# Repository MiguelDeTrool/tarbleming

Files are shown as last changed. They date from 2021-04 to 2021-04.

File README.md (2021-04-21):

# tarbleming
Arduino Nano based random looping sequencer Eurorack module

Tarbleming

This is my take on the Music Thing Modular Turing Machine/Mutable Instruments Marbles, in an easier to implement fashion, with easily available through-hole parts. I must warn anyone attempting this that I have not tested these exact PCBs, only an earlier prototype, that I then made minor modifications to for this version. I am quite confident that they will work, and feel free to send me a message if you decide to try this out. I wouldn't recommend this to a complete beginner, as I have provided no build guide.

You'll also notice a manual is missing. Basic functionality to get up and running is send it a clock signal. Each sequence, wether Gate or CV, can have it's own length. Tap the corresponding button for however many steps you want, then do a quick double tap to confirm that value. Turn a sequence's Randomness knob fully clockwise for it to constantly change, and fully counter-clockwise for it to lock in a looping pattern. And again, if you have questions, feel free to send a message.

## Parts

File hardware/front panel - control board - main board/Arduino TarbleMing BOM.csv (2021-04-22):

Id | Designator | Package | Quantity | Designation
1 | R4,R5,R6,R10,R8,R7,R1 | R_Axial_DIN0207_L6.3mm_D2.5mm_P7.62mm_Horizontal | 7 | 10K
2 | C14,C9,C8,C7,C6 | C_Disc_D3.8mm_W2.6mm_P2.50mm | 5 | 100n
3 | R32,R31 | R_Axial_DIN0207_L6.3mm_D2.5mm_P7.62mm_Horizontal | 2 | 1000
4 | Q4,Q5,Q3,Q2,Q1 | TO-92_Inline | 5 | 2N3904
5 | U5 | DIP-8_W7.62mm_Socket_LongPads | 1 | TL082
6 | U7 | DIP-8_W7.62mm_Socket_LongPads | 1 | MCP4822
7 | U4,U3 | DIP-8_W7.62mm_Socket_LongPads | 2 | MCP6002-xP
8 | J23,J22 | PinHeader_1x14_P2.54mm_Vertical | 2 | Conn_01x14
9 | J21,J20 | PinHeader_1x13_P2.54mm_Vertical | 2 | Conn_01x13
10 | R23,R30,R29,R27,R26,R28,R21,R20,R19,R18,R16,R12,R11,R9,R3,R2,R22 | R_Axial_DIN0207_L6.3mm_D2.5mm_P7.62mm_Horizontal | 17 | 100K
11 | D2,D1 | D_DO-15_P10.16mm_Horizontal | 2 | 1N4001
12 | SW4,SW3,SW2,SW1 | DPDT_Momentary_Push_Button_Switch | 4 | SW_Push_DPDT
13 | D5,D4,D3 | D_DO-35_SOD27_P7.62mm_Horizontal | 3 | 1N4148
14 | J12,J11,J10,J9,J8,J7,J6,J5,J4,J2,J1 | ModdedThonkiconn | 11 | ThonkiConn
15 | U6 | Arduino_Nano | 1 | Arduino_Nano_v3.x
16 | U2 | TO-220-3_Horizontal_TabDown | 1 | L7805
17 | U1 | TO-92_Inline | 1 | LM4040LP-5 (maybe could be replaced by a 5v zener diode in a pinch?)
18 | RV5,RV4,RV3,RV2,RV1 | ModdedPotentiometer | 5 | 10K
19 | R25,R24 | R_Axial_DIN0207_L6.3mm_D2.5mm_P7.62mm_Horizontal | 2 | 3300
20 | R14,R15,R17 | R_Axial_DIN0207_L6.3mm_D2.5mm_P7.62mm_Horizontal | 3 | 330
21 | R13 | R_Axial_DIN0207_L6.3mm_D2.5mm_P7.62mm_Horizontal | 1 | 50k
22 | J3 | PinHeader_2x05_P2.54mm_Vertical | 1 | Eurorack Power Header
23 | D8,D7,D6 | LED_D3.0mm | 3 | LED
24 | C3,C1 | CP_Radial_D6.3mm_P2.50mm | 2 | 100uF
25 | C13,C12,C11,C10,C2 | C_Disc_D3.8mm_W2.6mm_P2.50mm | 5 | 1n
26 | C5 | C_Disc_D3.8mm_W2.6mm_P2.50mm | 1 | 10n
27 | C4 | C_Disc_D3.8mm_W2.6mm_P2.50mm | 1 | 0.47µ

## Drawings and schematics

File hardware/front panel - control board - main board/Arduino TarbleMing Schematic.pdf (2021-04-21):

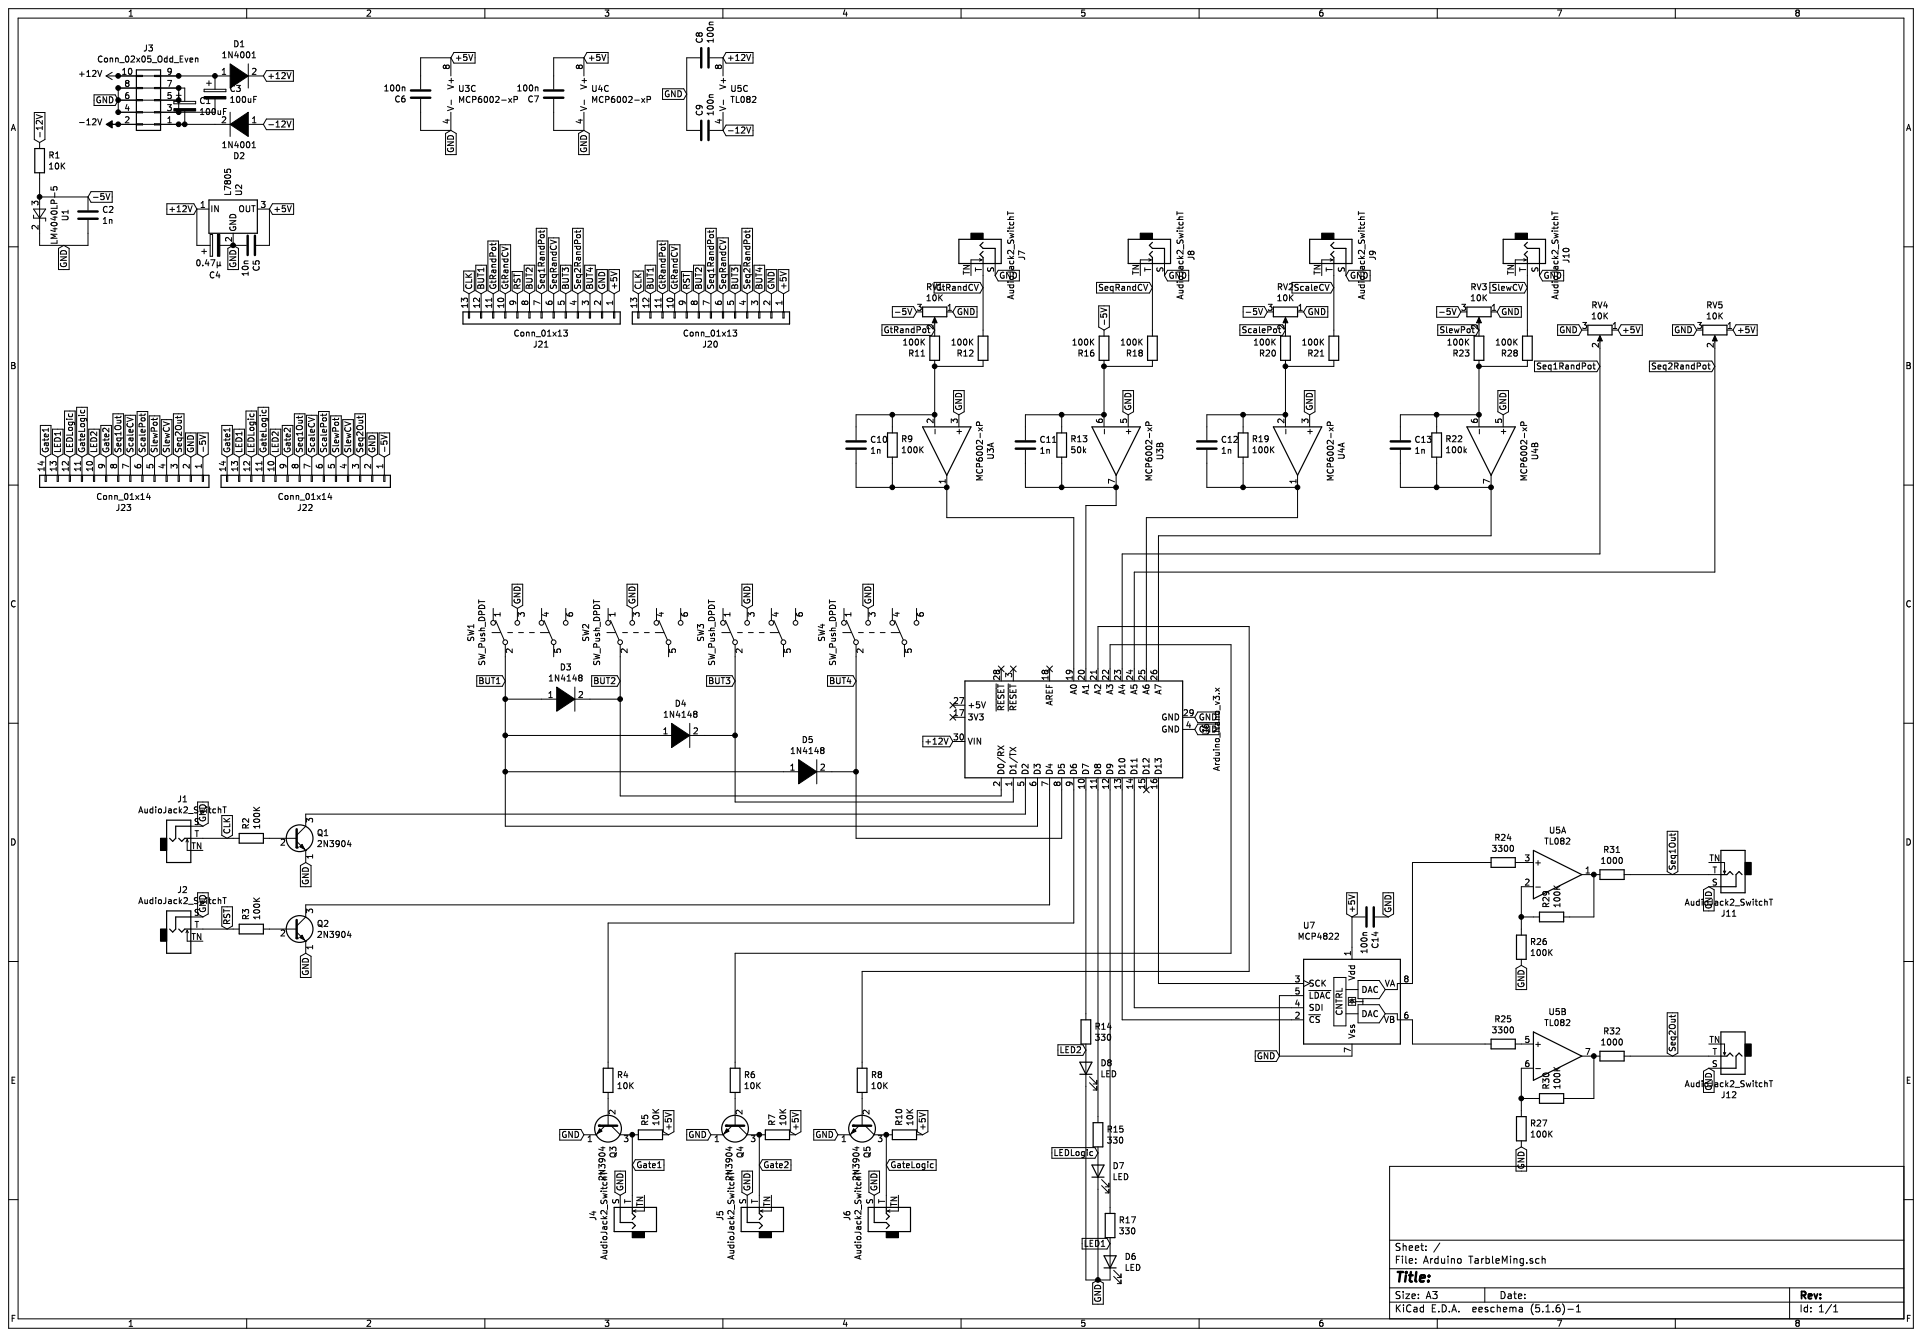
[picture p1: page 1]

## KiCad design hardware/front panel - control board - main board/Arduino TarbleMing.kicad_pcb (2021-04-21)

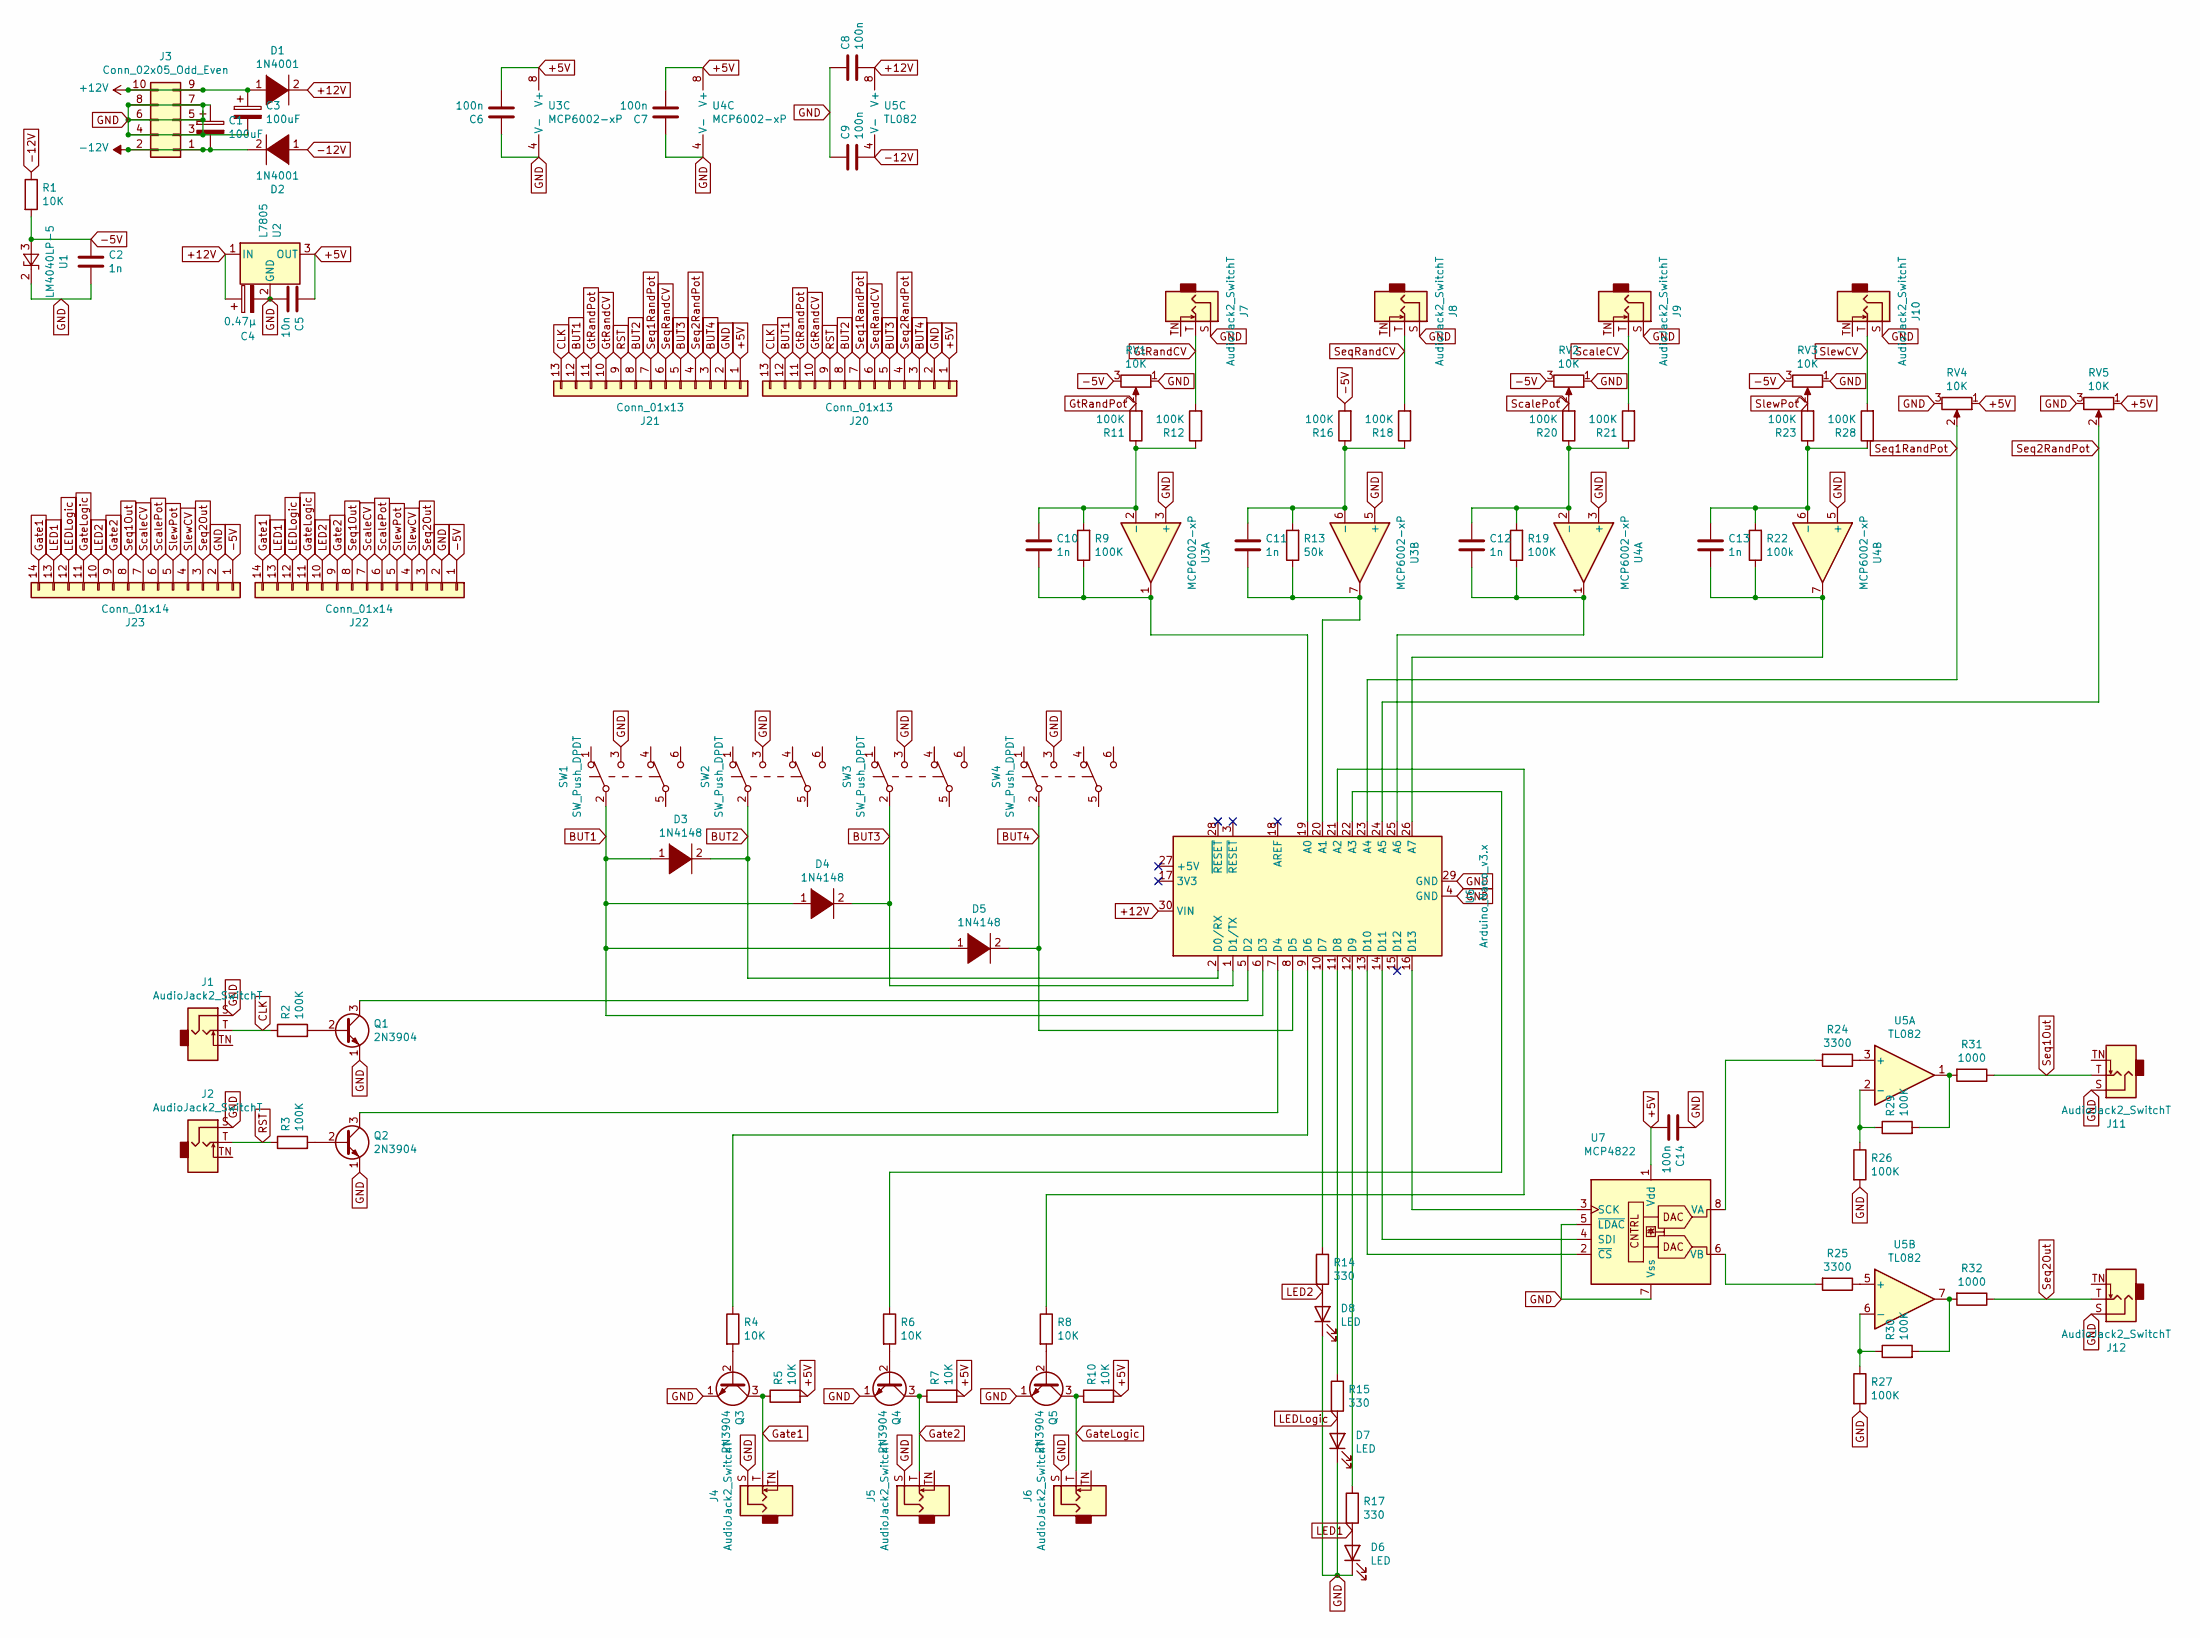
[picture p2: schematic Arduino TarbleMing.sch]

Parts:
C1, C3: 100uF; CP_Radial_D6.3mm_P2.50mm
C2, C10, C11, C12, C13: 1n; C_Disc_D3.8mm_W2.6mm_P2.50mm
C4: 0.47µ; C_Disc_D3.8mm_W2.6mm_P2.50mm
C5: 10n; C_Disc_D3.8mm_W2.6mm_P2.50mm
C6, C7, C8, C9, C14: 100n; C_Disc_D3.8mm_W2.6mm_P2.50mm
D1, D2: 1N4001; D_DO-15_P10.16mm_Horizontal
D3, D4, D5: 1N4148; D_DO-35_SOD27_P7.62mm_Horizontal
D6, D7, D8: LED; LED_D3.0mm
J1, J2, J4, J5, J6, J7, J8, J9, J10, J11, J12: AudioJack2_SwitchT; ModdedThonkiconn
J3: Conn_02x05_Odd_Even; PinHeader_2x05_P2.54mm_Vertical
J20, J21: Conn_01x13; PinHeader_1x13_P2.54mm_Vertical
J22, J23: Conn_01x14; PinHeader_1x14_P2.54mm_Vertical
Q1, Q2, Q3, Q4, Q5: 2N3904; TO-92_Inline
R1, R4, R5, R6, R7, R8, R10: 10K; R_Axial_DIN0207_L6.3mm_D2.5mm_P7.62mm_Horizontal
R2, R3, R9, R11, R12, R16, R18, R19, R20, R21, R23, R26, R27, R28, R29, R30: 100K; R_Axial_DIN0207_L6.3mm_D2.5mm_P7.62mm_Horizontal
R13: 50k; R_Axial_DIN0207_L6.3mm_D2.5mm_P7.62mm_Horizontal
R14, R15, R17: 330; R_Axial_DIN0207_L6.3mm_D2.5mm_P7.62mm_Horizontal
R22: 100k; R_Axial_DIN0207_L6.3mm_D2.5mm_P7.62mm_Horizontal
R24, R25: 3300; R_Axial_DIN0207_L6.3mm_D2.5mm_P7.62mm_Horizontal
R31, R32: 1000; R_Axial_DIN0207_L6.3mm_D2.5mm_P7.62mm_Horizontal
RV1, RV2, RV3, RV4, RV5: 10K; ModdedPotentiometer
SW1, SW2, SW3, SW4: SW_Push_DPDT; DPDT_Momentary_Push_Button_Switch
U1: LM4040LP-5; TO-92_Inline
U2: L7805; TO-220-3_Horizontal_TabDown
U3, U4: MCP6002-xP; DIP-8_W7.62mm_Socket_LongPads
U5: TL082; DIP-8_W7.62mm_Socket_LongPads
U6: Arduino_Nano_v3.x; Arduino_Nano
U7: MCP4822; DIP-8_W7.62mm_Socket_LongPads

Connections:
+5V: C5.1, C6.2, C7.2, C14.2, J20.1, J21.1, R5.2, R7.2, R10.2, RV4.1, RV5.1, U2.3 (OUT), U3.8 (V+), U4.8 (V+), U7.1 (Vdd)
+12V: C3.1, C4.1, C8.2, D1.1 (K), D1.2 (A), J3.9, J3.10, U2.1 (IN), U5.8 (V+), U6.30 (VIN)
-5V: C2.1, J22.1, J23.1, R1.2, R16.2, RV1.3, RV2.3, RV3.3, U1.3 (A)
-12V: C1.2, C9.2, D2.1 (K), D2.2 (A), J3.1, J3.2, R1.1, U5.4 (V-)
BUT1: D3.1 (K), D4.1 (K), D5.1 (K), J20.12, J21.12, SW1.2 (B), U6.6 (D3)
BUT2: D3.2 (A), J20.8, J21.8, SW2.2 (B), U6.2 (D0/RX)
BUT3: D4.2 (A), J20.5, J21.5, SW3.2 (B), U6.1 (D1/TX)
BUT4: D5.2 (A), J20.3, J21.3, SW4.2 (B), U6.8 (D5)
CLK: J1.T, J20.13, J21.13, R2.1
GND: C1.1, C2.2, C3.2, C4.2, C5.2, C6.1, C7.1, C8.1, C9.1, C14.1, D6.1 (K), D7.1 (K), D8.1 (K), J1.S, J2.S, J3.3, J3.4, J3.5, J3.6, J3.7, J3.8, J4.S, J5.S, J6.S, J7.S, J8.S, J9.S, J10.S, J11.S, J12.S, J20.2, J21.2, J22.2, J23.2, Q1.1 (E), Q2.1 (E), Q3.1 (E), Q4.1 (E), Q5.1 (E), R26.2, R27.2, RV1.1, RV2.1, RV3.1, RV4.3, RV5.3, SW1.3 (C), SW2.3 (C), SW3.3 (C), SW4.3 (C), U1.2 (K), U2.2 (GND), U3.3 (+), U3.4 (V-), U3.5 (+), U4.3 (+), U4.4 (V-), U4.5 (+), U6.4 (GND), U6.29 (GND), U7.5 (~LDAC), U7.7 (Vss)
Gate1: J4.T, J22.14, J23.14, Q3.3 (C), R5.1
Gate2: J5.T, J22.9, J23.9, Q4.3 (C), R7.1
GateLogic: J6.T, J22.11, J23.11, Q5.3 (C), R10.1
GtRandCV: J7.T, J20.10, J21.10, R12.2
GtRandPot: J20.11, J21.11, R11.2, RV1.2
LED1: D6.2 (A), J22.13, J23.13, R17.2
LED2: D8.2 (A), J22.10, J23.10, R14.2
LEDLogic: D7.2 (A), J22.12, J23.12, R15.2
unnamed: C10.1, R9.2, R11.1, R12.1, U3.2 (-)
unnamed: C10.2, R9.1, U3.1, U6.19 (A0)
unnamed: C11.1, R13.2, R16.1, R18.1, U3.6 (-)
unnamed: C11.2, R13.1, U3.7, U6.20 (A1)
unnamed: C12.1, R19.2, R20.1, R21.1, U4.2 (-)
unnamed: C12.2, R19.1, U4.1, U6.25 (A6)
unnamed: C13.1, R22.2, R23.1, R28.1, U4.6 (-)
unnamed: C13.2, R22.1, U4.7, U6.26 (A7)
unnamed: Q1.2 (B), R2.2
unnamed: Q1.3 (C), U6.5 (D2)
unnamed: Q2.2 (B), R3.2
unnamed: Q2.3 (C), U6.7 (D4)
unnamed: Q3.2 (B), R4.2
unnamed: Q4.2 (B), R6.2
unnamed: Q5.2 (B), R8.2
unnamed: R4.1, U6.9 (D6)
unnamed: R6.1, U6.22 (A3)
unnamed: R8.1, U6.21 (A2)
unnamed: R14.1, U6.10 (D7)
unnamed: R15.1, U6.11 (D8)
unnamed: R17.1, U6.12 (D9)
unnamed: R24.1, U5.3 (+)
unnamed: R24.2, U7.8 (VA)
unnamed: R25.1, U5.5 (+)
unnamed: R25.2, U7.6 (VB)
unnamed: R26.1, R29.1, U5.2 (-)
unnamed: R27.1, R30.1, U5.6 (-)
unnamed: R29.2, R31.2, U5.1
unnamed: R30.2, R32.2, U5.7
unnamed: U6.13 (D10), U7.2 (~CS)
unnamed: U6.14 (D11), U7.4 (SDI)
unnamed: U6.16 (D13), U7.3 (SCK)
RST: J2.T, J20.9, J21.9, R3.1
ScaleCV: J9.T, J22.7, J23.7, R21.2
ScalePot: J22.6, J23.6, R20.2, RV2.2
Seq1Out: J11.T, J22.8, J23.8, R31.1
Seq1RandPot: J20.7, J21.7, RV4.2, U6.23 (A4)
Seq2Out: J12.T, J22.3, J23.3, R32.1
Seq2RandPot: J20.4, J21.4, RV5.2, U6.24 (A5)
SeqRandCV: J8.T, J20.6, J21.6, R18.2
SlewCV: J10.T, J22.4, J23.4, R28.2
SlewPot: J22.5, J23.5, R23.2, RV3.2

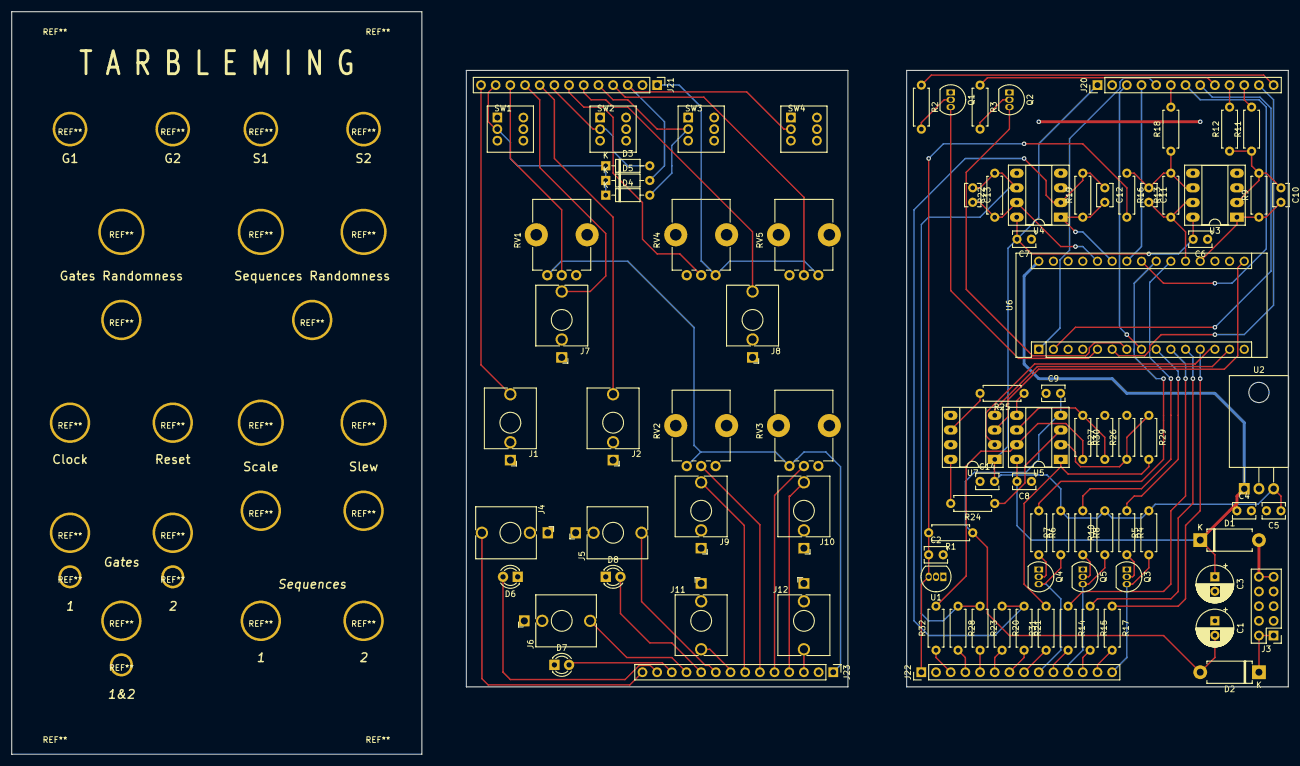
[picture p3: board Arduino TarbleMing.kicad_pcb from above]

Board: 2 copper layers, 220.9 x 128.5 mm, 91 parts (0 on the bottom side), 60 nets.

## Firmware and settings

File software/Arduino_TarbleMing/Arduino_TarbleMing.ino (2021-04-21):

#include <MCP48xx.h> // includes SPI functionality
MCP4822 dac(10);


// in-program numbers
int cv1Array[128];
int cv2Array[128];
bool gate1Array[128];
bool gate2Array[128];


int gateRandomness = 0;
int cv1Randomness = 0;
int cv2Randomness = 0;


int test = 0;
float cv1 = 0;
float cv2 = 0;
int targetCv1 = 0;
int targetCv2 = 0;

float slewRate = 0;
int scaleFactor = 0;


int counters[] = {0, 0, 0, 0};

int steps[] = {1, 1, 1, 1};

unsigned long startTimes[] = {0, 0, 0, 0};
int buttonCounts[] = {0, 0, 0, 0};

int doubleClickTime = 200;
int debounceTime = 100;

bool quantization = false; //Quantization not yet implemented, DAC doesn't seem to be precise enough anyway


// pin associations
const int buttonIntPin = 3;
const int button2Pin = 0;
const int button3Pin = 1;
const int button4Pin = 5;
const int buttonPins[] = {buttonIntPin, button2Pin, button3Pin, button4Pin};

const int clockPin = 2;
const int resetPin = 4;
const int gateRandPot = A0;
const int cv1RandPot = A4;
const int cv2RandPot = A5;
const int cvRandCv = A1;
const int scalePot = A6;
const int slewPot = A7;

const int LED1Pin = 9;
const int LEDLogicPin = 8;
const int LED2Pin = 7;

const int Gate1Pin = 6;
const int GateLogicPin = A2;
const int Gate2Pin = A3;


void setup() {
  pinMode(clockPin, INPUT_PULLUP);
  pinMode(resetPin, INPUT_PULLUP);

  pinMode(buttonIntPin, INPUT_PULLUP);
  pinMode(button2Pin, INPUT_PULLUP);
  pinMode(button3Pin, INPUT_PULLUP);
  pinMode(button4Pin, INPUT_PULLUP);

  pinMode(LED1Pin, OUTPUT);
  pinMode(LEDLogicPin, OUTPUT);
  pinMode(LED2Pin, OUTPUT);

  pinMode(Gate1Pin, OUTPUT);
  pinMode(GateLogicPin, OUTPUT);
  pinMode(Gate2Pin, OUTPUT);

  attachInterrupt(digitalPinToInterrupt(clockPin), gateChange, CHANGE);
  attachInterrupt(digitalPinToInterrupt(buttonIntPin), buttonPress, FALLING); // Inverted because buttons connected to ground

  dac.init();
  dac.turnOnChannelA();
  dac.turnOnChannelB();
  dac.setGainA(MCP4822::High);
  dac.setGainB(MCP4822::High);
  dac.setVoltageA(0);
  dac.setVoltageB(0);
  dac.updateDAC();
}


void loop() {
  cv1Randomness = analogRead(cv1RandPot) - (analogRead(cvRandCv) - 521);
  cv2Randomness = analogRead(cv2RandPot) - (analogRead(cvRandCv) - 521);

  gateRandomness = - analogRead(gateRandPot) + 1023;
  slewRate = 1 + pow(analogRead(slewPot), 3) / 1000000;
  scaleFactor = (- analogRead(scalePot) + 1023) * 4;

  test = random(1024);

  cv1 = slewing(cv1, targetCv1);
  cv2 = slewing(cv2, targetCv2);

  dac.setVoltageA(int(cv1));
  dac.setVoltageB(int(cv2));

  dac.updateDAC();

}

void gateChange() {
  if (digitalRead(clockPin) == LOW) {
    newStep();
  } else {
    endStep();
  }
}

void newStep() {

  if (digitalRead(resetPin) == LOW) {
    for (int i = 3; i >= 0; i--) {
      counters[i] = 0;
    }
  }

  for (int i = 3; i >= 0; i--) {
    counters[i] ++;
    counters[i] = counters[i] % steps[i];
  }


  if  (test < gateRandomness) {
    gate1Array[counters[0]] = random(2);
    gate2Array[counters[1]] = random(2);
  }

  if  (test < cv1Randomness) {
    cv1Array[counters[2]] = random(scaleFactor);
  }
  if  (test < cv2Randomness) {
    cv2Array[counters[3]] = random(scaleFactor);
  }

  // for Transistors
  digitalWrite(Gate1Pin, !gate1Array[counters[0]]);
  digitalWrite(GateLogicPin, !(gate1Array[counters[0]] && gate2Array[counters[1]]));
  digitalWrite(Gate2Pin, !gate2Array[counters[1]]);


  // for LEDs

  digitalWrite(LED1Pin, gate1Array[counters[0]]);
  digitalWrite(LEDLogicPin, gate1Array[counters[0]] && gate2Array[counters[1]]);
  digitalWrite(LED2Pin, gate2Array[counters[1]]);


  targetCv1 = cv1Array[counters[2]];
  targetCv2 = cv2Array[counters[3]];

  if (quantization == true) { //Quantization not yet implemented, DAC doesn't seem to be precise enough anyway
    quantize(targetCv1);
    quantize(targetCv2);
  }
}


void endStep() {
  // for TRANSISTORS
  digitalWrite(Gate1Pin, HIGH);
  digitalWrite(GateLogicPin, HIGH);
  digitalWrite(Gate2Pin, HIGH);

  // for LEDs
  digitalWrite(LED1Pin, LOW);
  digitalWrite(LEDLogicPin, LOW);
  digitalWrite(LED2Pin, LOW);
}



void buttonPress() {
  for (int i = 3; i >= 0; i--) {
    if (digitalRead(buttonPins[i]) == LOW) {
      if (millis() - startTimes[i] < debounceTime) {
      }
      else if (millis() - startTimes[i] < doubleClickTime) {
        buttonCounts[i] = max(buttonCounts[i] - 1, 0);
        steps[i] = min(buttonCounts[i], 127);
        buttonCounts[i] = 0;
        startTimes[i]   = millis();
      }
      else {
        startTimes[i] = millis();
        buttonCounts[i]++;
      }
      break;
    }
  }
}


int quantize(int x) {
  x = float(x);
  x = x - x % 83,33333333333;
  return int(x + 0.5);
}

float slewing(float x, int y) {
  if (abs(x - y) <= slewRate) {
    x = y;
  }
  else if (int(x + 0.5) > y) {
    x = x - slewRate;
  }
  else if (int(x + 0.5) < y) {
    x = x + slewRate;
  }
  return x;
}
